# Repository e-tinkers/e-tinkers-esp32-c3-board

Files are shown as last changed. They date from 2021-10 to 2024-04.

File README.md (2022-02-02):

# E-Tinkers ESP32-C3 Board

E-Tinkers ESP32-C3 Board is a ESP32-C3 dev board base on ESP32-C3-WROOM-02 module from  Expressif, unlike the official ESP-C3-DevKitM-1 or ESP32-C3-DevKitC-02, E-Tinkers ESP32-C3 Board does not has the USB Type-C port and the ESPLink on-board programmer, but it does include an on-board 600mA LDO and break out all the GPIO pins. It is designed for using as a WiFi/BLE shield or to integrated with another MCU and/or sensors, and before creating your own customizing design, you need an ESP32-C3 evaluation board for rapid prototype, in both cases USB port is probably not needed in the end product.

## Specification and Key features

Component|Detail |
----|----|
MCU         | 32-bit single-core RISC-V |
ROM         | 384KB |
SRAM        | 400KB(16KB for cache) |
Flash       | 4MB |
WiFi        | IEEE 802.11bgn |
Bluetooth   | BLE 5.0 & mesh |
GPIO        | 22 |
SPI         | 3 |
UART        | 2 |
I2C         | 1 |
RMT         | 2 Transmit + 2 Receive |
DMA         | 3 Transmit + 3 Receive |
LED-PWMC    | 6 channels |
TWAI        | 1 |
ADC         | 2 x 12bit, 6 channels |
Temp sensor | 1 |
Timer       | 6 |
Security    | OTP/AES/SHA/RSA/RNG/HMAC |

## Pin Assignements
All available GPIO pins of the ESP32-C3-WROOM-02 are broken out to the pin headers on the board.
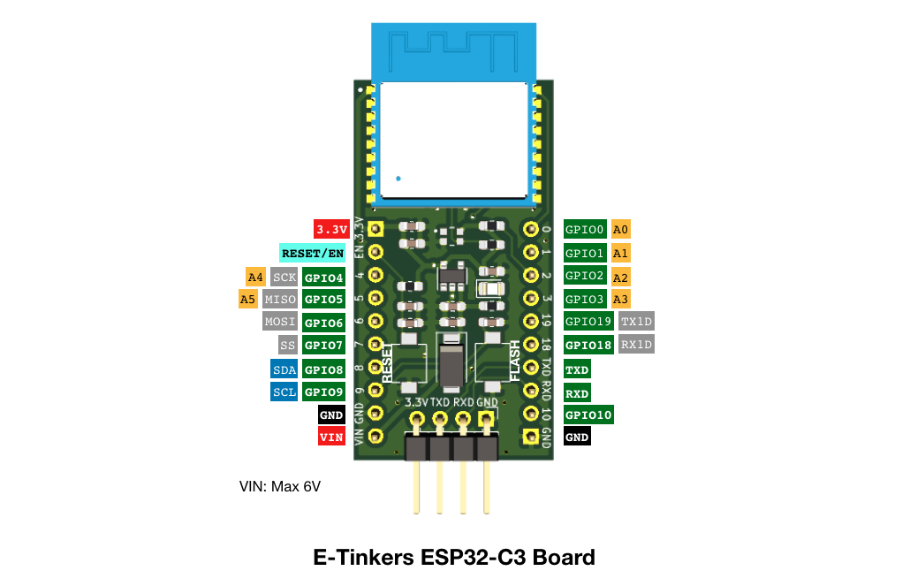
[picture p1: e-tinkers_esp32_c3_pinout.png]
E-Tinkers ESP32-C3 Board pinout


## Firmware
Programming can be done using a USB-TTL Adaptor. The *Firmware* folder contains the firmware binary code , bootloader, and partition table for testing and demo purpose. Use [esptool](https://github.com/espressif/esptool) to upload the code to the board.

```
esptool.py --chip esp32c3 \
	--port /dev/cu.SLAB_USBtoUART \
	write_flash \
	--flash_mode dio \
	--flash_size 4MB \
	--flash_freq 80m \
	0x0 bootloader.bin \
	0x8000 partitions.bin \
	0x10000 firmware.bin
```

## Source Code
The source code for the firmware used can be found at this [repository](https://github.com/e-tinkers/esp32-c3-blinking).

## Reference
### esp-idf
https://github.com/espressif/esp-idf
### esp32-c3 get-started
https://docs.espressif.com/projects/esp-idf/en/latest/esp32c3/get-started/
### esp32-c3
https://www.espressif.com/en/products/socs/esp32-c3

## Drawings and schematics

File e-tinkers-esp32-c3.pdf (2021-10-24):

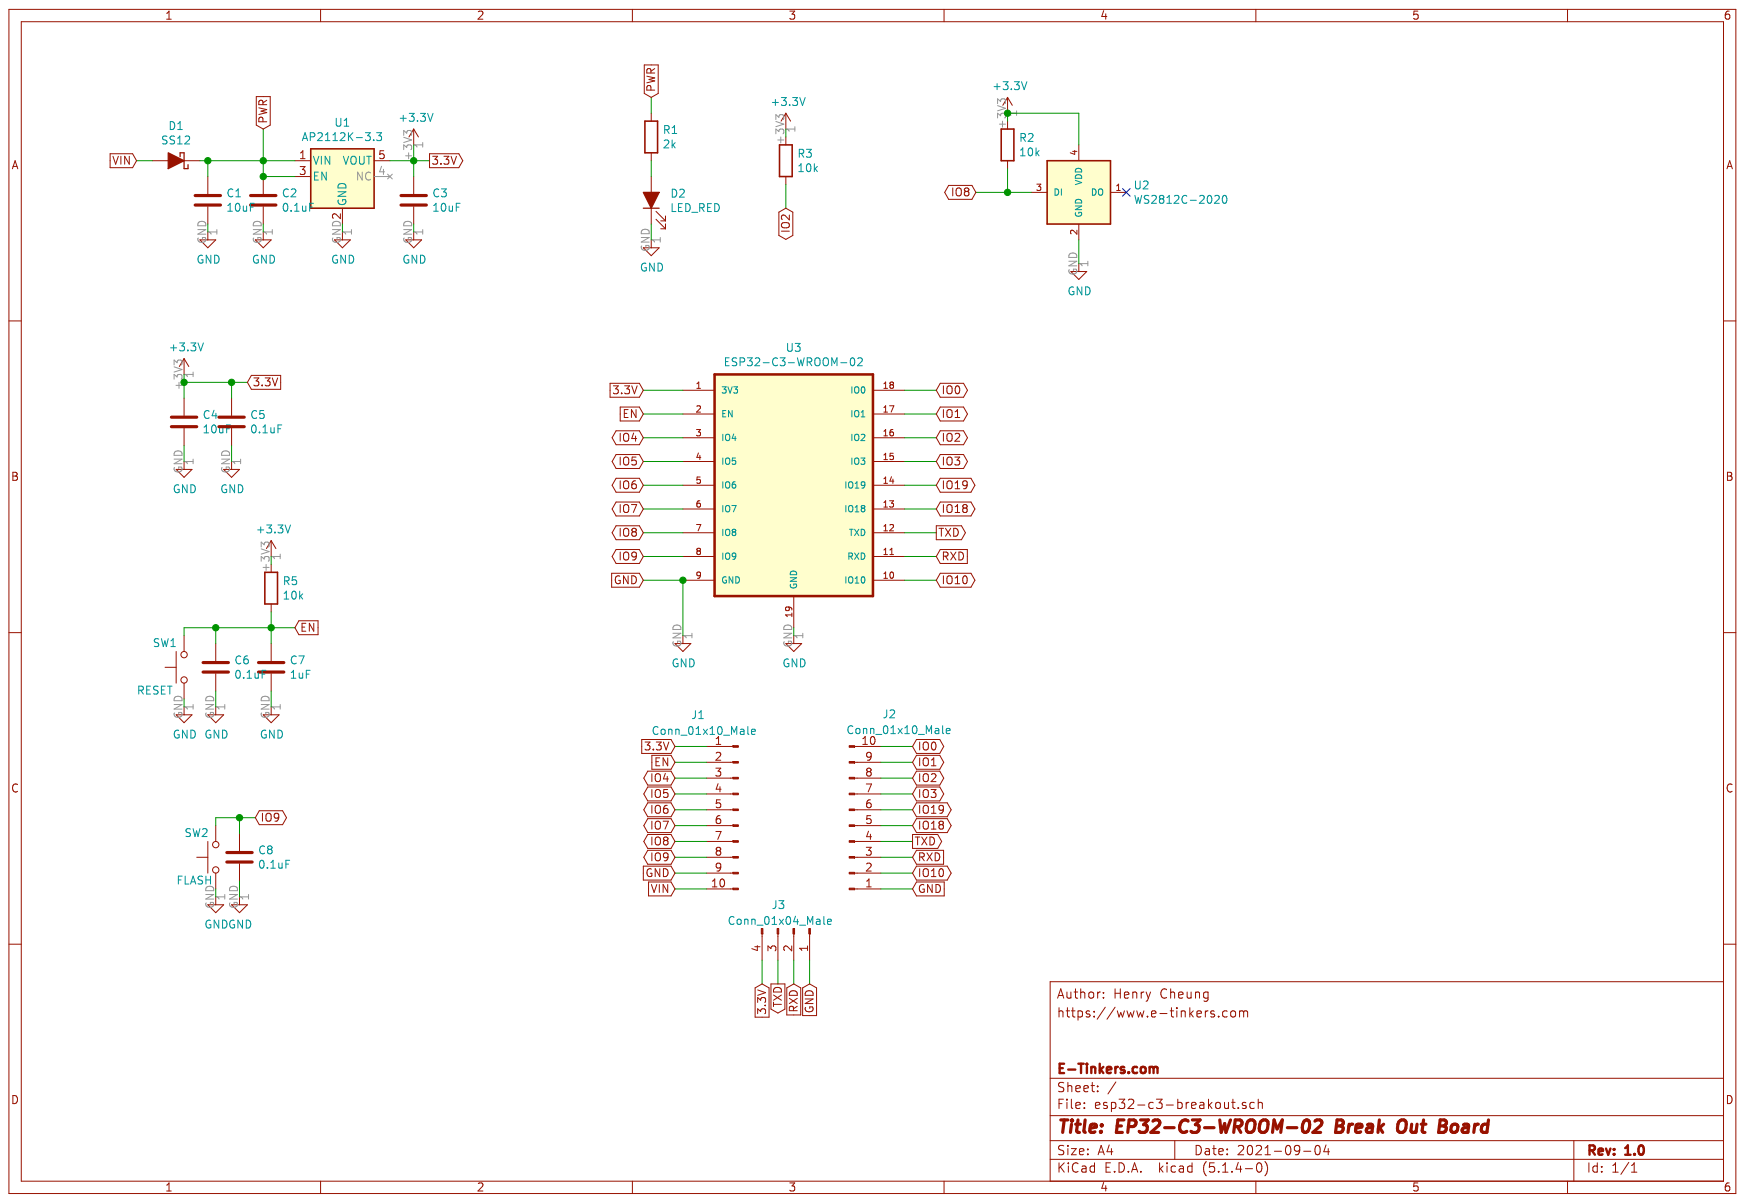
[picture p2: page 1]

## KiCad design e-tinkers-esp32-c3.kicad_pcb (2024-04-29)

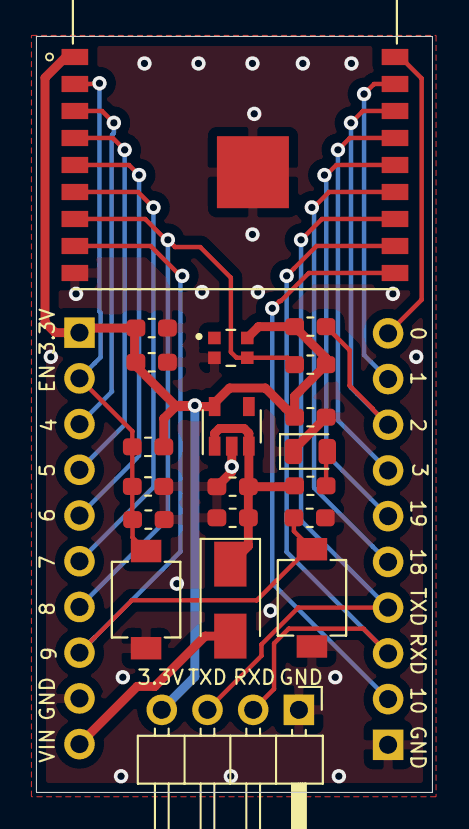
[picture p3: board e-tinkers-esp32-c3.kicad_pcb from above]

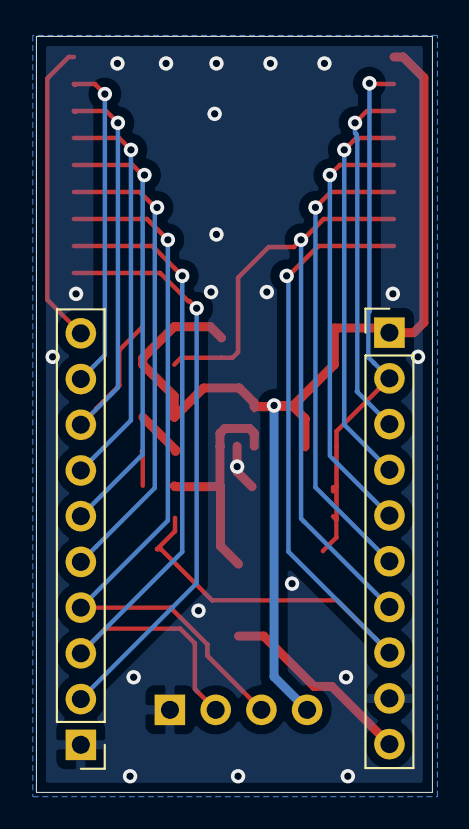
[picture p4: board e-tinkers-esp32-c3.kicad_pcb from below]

Board: 2 copper layers, 22.0 x 42.0 mm, 22 parts (2 on the bottom side), 21 nets.

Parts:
C1, C3, C4: 10uF; C_0603_1608Metric_Pad1.05x0.95mm_HandSolder
C2, C5, C6, C8: 0.1uF; C_0603_1608Metric_Pad1.05x0.95mm_HandSolder
C7: 1uF; C_0603_1608Metric_Pad1.05x0.95mm_HandSolder
D1: SS12; D_SMA
D2: LED_RED; LED_0805_2012Metric
J1, J2: Conn_01x10_Male; PinHeader_1x10_P2.54mm_Vertical
J3: Conn_01x04_Male; PinHeader_1x04_P2.54mm_Horizontal
R1: 2k; R_0603_1608Metric_Pad1.05x0.95mm_HandSolder
R2, R3, R5: 10k; R_0603_1608Metric_Pad1.05x0.95mm_HandSolder
SW1: RESET; SW_TS-1185-X-X
SW2: FLASH; SW_TS-1185-X-X
U1: AP2112K-3.3; SOT-23-5
U2: WS2812C-2020; LED_WS2812C-2020
U3: ESP32-C3-WROOM-02; MODULE_ESP32-C3-WROOM-02

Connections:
3.3V: C3.1, C4.1, C5.1, J1.1, J3.4, R2.1, R3.1, R5.1, U1.5, U2.4, U3.1
EN: C6.1, C7.1, J1.2, R5.2, SW1.2, U3.2
GND: C1.2, C2.2, C3.2, C4.2, C5.2, C6.2, C7.2, C8.2, D2.1, J1.9, J2.1, J3.1, SW1.1, SW2.1, U1.2, U2.2, U3.9, U3.19
IO0: J2.10, U3.18
IO1: J2.9, U3.17
IO2: J2.8, R3.2, U3.16
IO3: J2.7, U3.15
IO4: J1.3, U3.3
IO5: J1.4, U3.4
IO6: J1.5, U3.5
IO7: J1.6, U3.6
IO8: J1.7, R2.2, U2.3, U3.7
IO9: C8.1, J1.8, SW2.2, U3.8
IO10: J2.2, U3.10
IO18: J2.5, U3.13
IO19: J2.6, U3.14
unnamed: D2.2, R1.2
PWR: C1.1, C2.1, D1.1, R1.1, U1.1, U1.3
RXD: J2.3, J3.2, U3.11
TXD: J2.4, J3.3, U3.12
VIN: D1.2, J1.10

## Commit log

2021-10-24 inital commit
    [e-tinkers-esp32-c3.kicad_pcb, e-tinkers-esp32-c3.sch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]
2024-04-28 update to kicad 6
    [e-tinkers-esp32-c3.kicad_sch]
